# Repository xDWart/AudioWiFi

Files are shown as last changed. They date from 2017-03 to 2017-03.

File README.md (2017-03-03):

# AudioWiFi
Самодельный USB-свисток с микрофоном, STM32 и ESP8266 на борту

**AudioWiFi.ioc** - проект STM32CubeMX (v.4.15.0)

**EWARM\Project.eww** - проект IAR Embedded Workbench IDE for ARM (v.7.70.1)

**EagleCAD\** - проект EagleCAD (v.7.7.0)

**ogg.php** - файл серверной части на PHP

**20170303172953.spx** - пример записанного звука

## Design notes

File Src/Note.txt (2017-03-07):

Минимально рабочие
CSTACK 0x600
HEAP 1400

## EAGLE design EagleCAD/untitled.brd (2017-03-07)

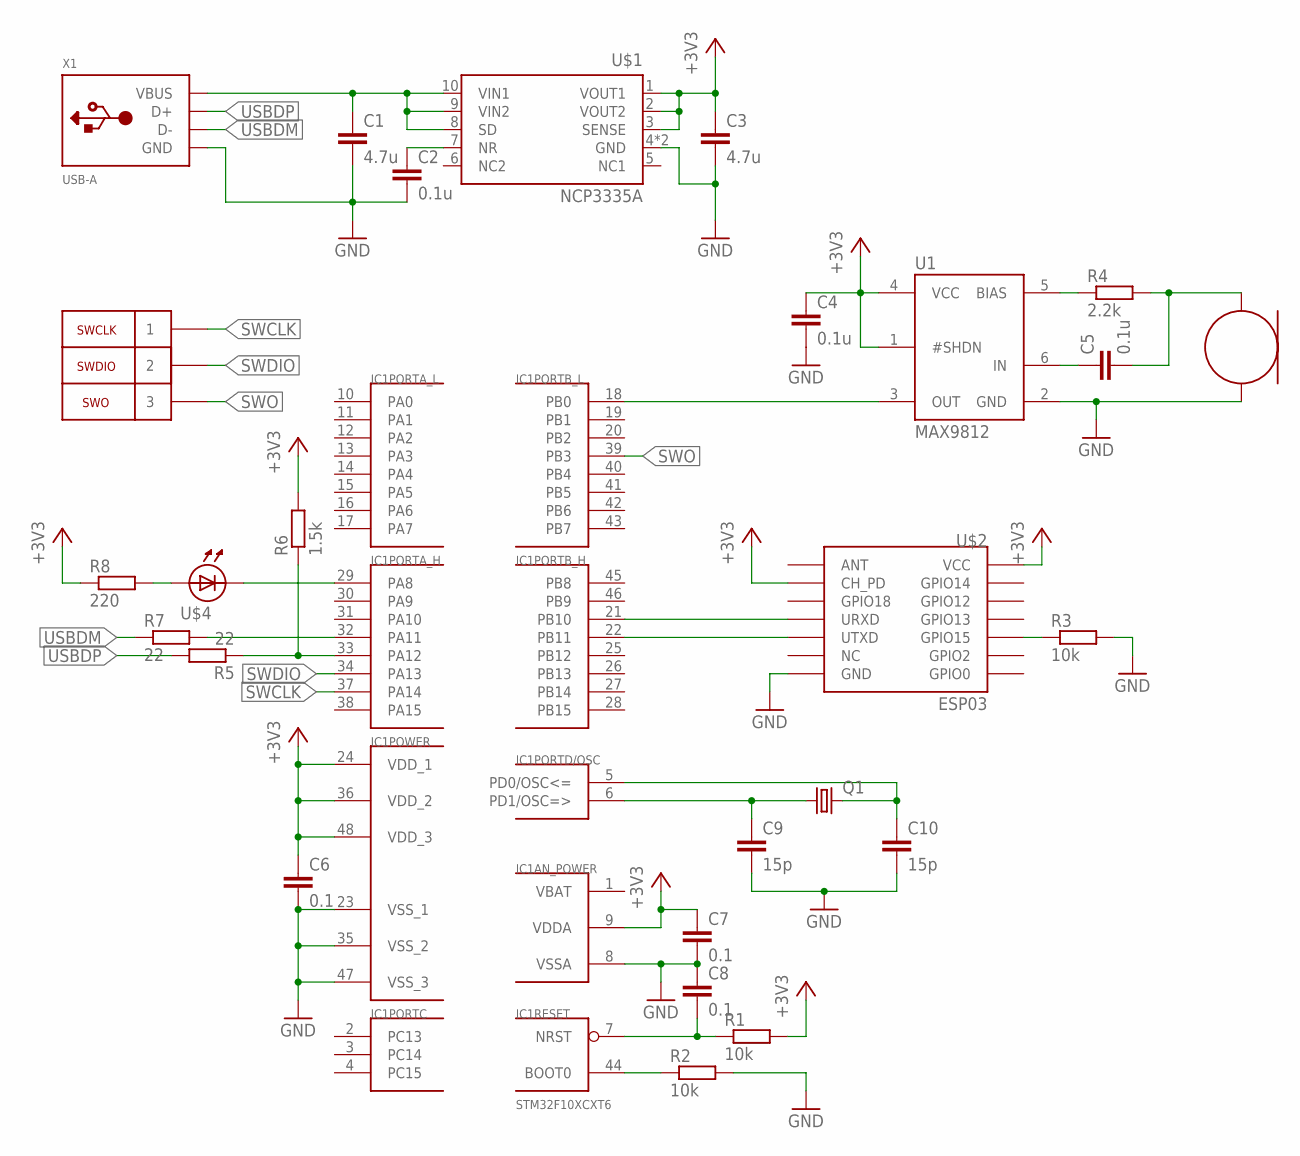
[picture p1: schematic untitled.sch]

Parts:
C1, C3: 4.7u; C0805
C2: 0.1u; C0805
C4, C5: 0.1u; C0603
C6, C7, C8: 0.1; C0805
C9, C10: 15p; C0603
IC1: STM32F10XCXT6; TQFP48
Q1: CRYSTAL; DSX321G
R1, R2, R3: 10k; R0805
R4: 2.2k; R0603
R5, R7: 22; R0805
R6: 1.5k; R0805
R8: 220; R0805
U1: MAX9812; SC-70-6
U$1: NCP3335A; DFN10-3X3
U$2: ESP03
U$3: MIC
U$4: LED1206; R1206
U$5: PLS2-3
X1: USB-A; MOLEX_480371000

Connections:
+3V3: C3.1, C4.1, C6.1, C7.1, IC1.9 (VDDA), IC1.24 (VDD_1), IC1.36 (VDD_2), IC1.48 (VDD_3), R1.2, R6.2, R8.1, U1.1 (#SHDN), U1.4 (VCC), U$1.1 (VOUT1), U$1.2 (VOUT2), U$1.3 (SENSE), U$2.CH_PD, U$2.VCC
GND: C1.2, C2.2, C3.2, C4.2, C6.2, C7.2, C8.1, C9.2, C10.2, IC1.8 (VSSA), IC1.23 (VSS_1), IC1.35 (VSS_2), IC1.47 (VSS_3), R2.2, R3.2, U1.2 (GND), U$1.4 (GND), U$1.EXP (GND), U$2.GND, U$3.P$2, X1.4 (GND)
unnamed: C1.1, U$1.8 (SD), U$1.9 (VIN2), U$1.10 (VIN1), X1.1 (VBUS)
unnamed: C2.1, U$1.7 (NR)
unnamed: C8.2, IC1.7 (NRST), R1.1
unnamed: IC1.44 (BOOT0), R2.1
unnamed: IC1.21 (PB10), U$2.URXD
unnamed: IC1.22 (PB11), U$2.UTXD
unnamed: R3.1, U$2.GPIO15
unnamed: IC1.18 (PB0), U1.3 (OUT)
unnamed: R4.1, U1.5 (BIAS)
unnamed: C5.1, U1.6 (IN)
unnamed: C5.2, R4.2, U$3.P$1
unnamed: IC1.33 (PA12), R5.1, R6.1
unnamed: IC1.32 (PA11), R7.2
unnamed: C9.1, IC1.6 (PD1/OSC=>), Q1.P$1 (1)
unnamed: C10.1, IC1.5 (PD0/OSC<=), Q1.P$3 (2)
unnamed: R8.2, U$4.1
unnamed: IC1.29 (PA8), U$4.2
SWCLK: IC1.37 (PA14), U$5.P$1 (1)
SWDIO: IC1.34 (PA13), U$5.P$2 (2)
SWO: IC1.39 (PB3), U$5.P$3 (3)
USBDM: R7.1, X1.2 (D-)
USBDP: R5.2, X1.3 (D+)
VBAT: IC1.1 (VBAT)

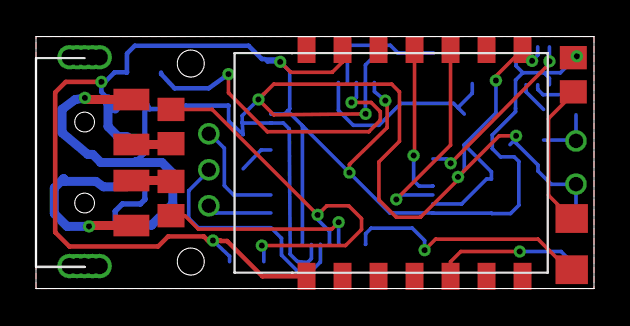
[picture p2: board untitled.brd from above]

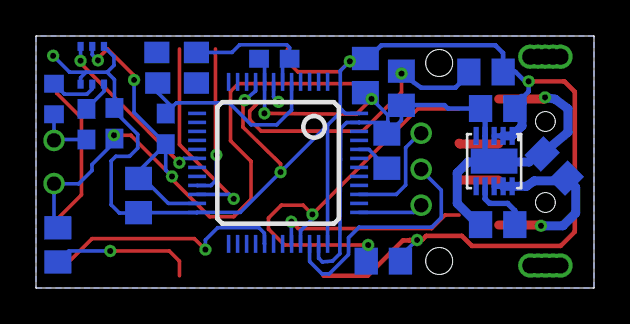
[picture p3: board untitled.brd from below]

Board: 2 copper layers, 31.0 x 14.0 mm, 27 parts (19 on the bottom side), 24 nets.

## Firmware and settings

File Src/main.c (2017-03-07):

/**
  ******************************************************************************
  * File Name          : main.c
  * Description        : Main program body
  ******************************************************************************
  *
  * COPYRIGHT(c) 2017 STMicroelectronics
  *
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
  ******************************************************************************
  */
/* Includes ------------------------------------------------------------------*/
#include "stm32f1xx_hal.h"
#include "usb_device.h"

/* USER CODE BEGIN Includes */
#include "public.h"
#include "my/wifi.h"
#include "my/speexx.h"
#include "my/events.h"

/* USER CODE END Includes */

ADC_HandleTypeDef hadc1;
DMA_HandleTypeDef hdma_adc1;

TIM_HandleTypeDef htim2;
TIM_HandleTypeDef htim3;

UART_HandleTypeDef huart3;
DMA_HandleTypeDef hdma_usart3_tx;

/* USER CODE BEGIN PV */
ADC_HandleTypeDef hadc1;
DMA_HandleTypeDef hdma_adc1;

TIM_HandleTypeDef htim3;

UART_HandleTypeDef huart3;
DMA_HandleTypeDef hdma_usart3_tx;
DMA_HandleTypeDef hdma_usart3_rx;
/* USER CODE END PV */

void SystemClock_Config(void);
void Error_Handler(void);
static void MX_GPIO_Init(void);
static void MX_DMA_Init(void);
static void MX_ADC1_Init(void);
static void MX_TIM2_Init(void);
static void MX_TIM3_Init(void);
static void MX_USART3_UART_Init(void);

/* USER CODE BEGIN PFP */

/* USER CODE END PFP */

int main(void)
{

  /* USER CODE BEGIN 1 */
  ClrEvents();
  Speex_Init();
  /* USER CODE END 1 */

  /* MCU Configuration----------------------------------------------------------*/

  /* Reset of all peripherals, Initializes the Flash interface and the Systick. */
  HAL_Init();

  /* Configure the system clock */
  SystemClock_Config();

  /* Initialize all configured peripherals */
  MX_GPIO_Init();
  MX_DMA_Init();
  MX_ADC1_Init();
  MX_TIM2_Init();
  MX_TIM3_Init();
  MX_USART3_UART_Init();
  MX_USB_DEVICE_Init();

  /* USER CODE BEGIN 2 */
  if(HAL_TIM_Base_Start_IT(&htim2) != HAL_OK) Error_Handler();
  if(HAL_TIM_Base_Start_IT(&htim3) != HAL_OK) Error_Handler();
  if(HAL_ADC_Start_DMA(&hadc1,(uint32_t*)&IN_Buffer[0],FRAME_SIZE*2) != HAL_OK) Error_Handler();
  /* USER CODE END 2 */

  /* Infinite loop */
  /* USER CODE BEGIN WHILE */
  Del_UART_ALL_Nextoperate();
  Add_UART_nextoperate_AT(ATE0,true);
  Add_UART_nextoperate_AT(AT_CWJAP,true);
  
  HAL_Delay(1000);
  Led_off; 
  HAL_UART_Receive_IT(&huart3,&UART_RxByte,1);
  SetEvent(EVNT_UART_SEND,EVENT_DONE); 
  while (1)
  {   
    if (TestEvent_Done(EVNT_UART_SEND)) {
      UART_send();
    }

    if (TestEvent_Done(EVNT_UART_RECEIVE)) {
      UART_parser();
    }
    
    EncodingVoice();

    if (TestEvent_Done(EVNT_VAD_DETECT)) {
      VAD_detect = false;
    }
    
    if (TestEvent_Done(EVNT_LED_SIGNAL)) {
        Led_inv;
        if (VAD_detect) SetEvent(EVNT_LED_SIGNAL,200);
          else if (ReadySendData) SetEvent(EVNT_LED_SIGNAL,1000);
                             else SetEvent(EVNT_LED_SIGNAL,3000);
    }    

  /* USER CODE END WHILE */

  /* USER CODE BEGIN 3 */
  }
  /* USER CODE END 3 */

}

/** System Clock Configuration
*/
void SystemClock_Config(void)
{

  RCC_OscInitTypeDef RCC_OscInitStruct;
  RCC_ClkInitTypeDef RCC_ClkInitStruct;
  RCC_PeriphCLKInitTypeDef PeriphClkInit;

  RCC_OscInitStruct.OscillatorType = RCC_OSCILLATORTYPE_HSE;
  RCC_OscInitStruct.HSEState = RCC_HSE_ON;
  RCC_OscInitStruct.HSEPredivValue = RCC_HSE_PREDIV_DIV1;
  RCC_OscInitStruct.PLL.PLLState = RCC_PLL_ON;
  RCC_OscInitStruct.PLL.PLLSource = RCC_PLLSOURCE_HSE;
  RCC_OscInitStruct.PLL.PLLMUL = RCC_PLL_MUL9;
  if (HAL_RCC_OscConfig(&RCC_OscInitStruct) != HAL_OK)
  {
    Error_Handler();
  }

  RCC_ClkInitStruct.ClockType = RCC_CLOCKTYPE_HCLK|RCC_CLOCKTYPE_SYSCLK
                              |RCC_CLOCKTYPE_PCLK1|RCC_CLOCKTYPE_PCLK2;
  RCC_ClkInitStruct.SYSCLKSource = RCC_SYSCLKSOURCE_PLLCLK;
  RCC_ClkInitStruct.AHBCLKDivider = RCC_SYSCLK_DIV1;
  RCC_ClkInitStruct.APB1CLKDivider = RCC_HCLK_DIV2;
  RCC_ClkInitStruct.APB2CLKDivider = RCC_HCLK_DIV1;
  if (HAL_RCC_ClockConfig(&RCC_ClkInitStruct, FLASH_LATENCY_2) != HAL_OK)
  {
    Error_Handler();
  }

  PeriphClkInit.PeriphClockSelection = RCC_PERIPHCLK_ADC|RCC_PERIPHCLK_USB;
  PeriphClkInit.AdcClockSelection = RCC_ADCPCLK2_DIV6;
  PeriphClkInit.UsbClockSelection = RCC_USBCLKSOURCE_PLL_DIV1_5;
  if (HAL_RCCEx_PeriphCLKConfig(&PeriphClkInit) != HAL_OK)
  {
    Error_Handler();
  }

  HAL_SYSTICK_Config(HAL_RCC_GetHCLKFreq()/1000);

  HAL_SYSTICK_CLKSourceConfig(SYSTICK_CLKSOURCE_HCLK);

  /* SysTick_IRQn interrupt configuration */
  HAL_NVIC_SetPriority(SysTick_IRQn, 0, 0);
}

/* ADC1 init function */
static void MX_ADC1_Init(void)
{

  ADC_ChannelConfTypeDef sConfig;

    /**Common config 
    */
  hadc1.Instance = ADC1;
  hadc1.Init.ScanConvMode = ADC_SCAN_DISABLE;
  hadc1.Init.ContinuousConvMode = DISABLE;
  hadc1.Init.DiscontinuousConvMode = DISABLE;
  hadc1.Init.ExternalTrigConv = ADC_EXTERNALTRIGCONV_T3_TRGO;
  hadc1.Init.DataAlign = ADC_DATAALIGN_RIGHT;
  hadc1.Init.NbrOfConversion = 1;
  if (HAL_ADC_Init(&hadc1) != HAL_OK)
  {
    Error_Handler();
  }

    /**Configure Regular Channel 
    */
  sConfig.Channel = ADC_CHANNEL_8;
  sConfig.Rank = 1;
  sConfig.SamplingTime = ADC_SAMPLETIME_1CYCLE_5;
  if (HAL_ADC_ConfigChannel(&hadc1, &sConfig) != HAL_OK)
  {
    Error_Handler();
  }

}

/* TIM2 init function */
static void MX_TIM2_Init(void)
{

  TIM_ClockConfigTypeDef sClockSourceConfig;
  TIM_MasterConfigTypeDef sMasterConfig;

  htim2.Instance = TIM2;
  htim2.Init.Prescaler = 1;
  htim2.Init.CounterMode = TIM_COUNTERMODE_UP;
  htim2.Init.Period = 35999;
  htim2.Init.ClockDivision = TIM_CLOCKDIVISION_DIV1;
  if (HAL_TIM_Base_Init(&htim2) != HAL_OK)
  {
    Error_Handler();
  }

  sClockSourceConfig.ClockSource = TIM_CLOCKSOURCE_INTERNAL;
  if (HAL_TIM_ConfigClockSource(&htim2, &sClockSourceConfig) != HAL_OK)
  {
    Error_Handler();
  }

  sMasterConfig.MasterOutputTrigger = TIM_TRGO_RESET;
  sMasterConfig.MasterSlaveMode = TIM_MASTERSLAVEMODE_DISABLE;
  if (HAL_TIMEx_MasterConfigSynchronization(&htim2, &sMasterConfig) != HAL_OK)
  {
    Error_Handler();
  }

}

/* TIM3 init function */
static void MX_TIM3_Init(void)
{

  TIM_ClockConfigTypeDef sClockSourceConfig;
  TIM_MasterConfigTypeDef sMasterConfig;

  htim3.Instance = TIM3;
  htim3.Init.Prescaler = 0;
  htim3.Init.CounterMode = TIM_COUNTERMODE_UP;
  htim3.Init.Period = 8999;
  htim3.Init.ClockDivision = TIM_CLOCKDIVISION_DIV1;
  if (HAL_TIM_Base_Init(&htim3) != HAL_OK)
  {
    Error_Handler();
  }

  sClockSourceConfig.ClockSource = TIM_CLOCKSOURCE_INTERNAL;
  if (HAL_TIM_ConfigClockSource(&htim3, &sClockSourceConfig) != HAL_OK)
  {
    Error_Handler();
  }

  sMasterConfig.MasterOutputTrigger = TIM_TRGO_UPDATE;
  sMasterConfig.MasterSlaveMode = TIM_MASTERSLAVEMODE_DISABLE;
  if (HAL_TIMEx_MasterConfigSynchronization(&htim3, &sMasterConfig) != HAL_OK)
  {
    Error_Handler();
  }

}

/* USART3 init function */
static void MX_USART3_UART_Init(void)
{

  huart3.Instance = USART3;
  huart3.Init.BaudRate = 115200;
  huart3.Init.WordLength = UART_WORDLENGTH_8B;
  huart3.Init.StopBits = UART_STOPBITS_1;
  huart3.Init.Parity = UART_PARITY_NONE;
  huart3.Init.Mode = UART_MODE_TX_RX;
  huart3.Init.HwFlowCtl = UART_HWCONTROL_NONE;
  huart3.Init.OverSampling = UART_OVERSAMPLING_16;
  if (HAL_UART_Init(&huart3) != HAL_OK)
  {
    Error_Handler();
  }

}

/** 
  * Enable DMA controller clock
  */
static void MX_DMA_Init(void) 
{
  /* DMA controller clock enable */
  __HAL_RCC_DMA1_CLK_ENABLE();

  /* DMA interrupt init */
  /* DMA1_Channel1_IRQn interrupt configuration */
  HAL_NVIC_SetPriority(DMA1_Channel1_IRQn, 0, 0);
  HAL_NVIC_EnableIRQ(DMA1_Channel1_IRQn);
  /* DMA1_Channel2_IRQn interrupt configuration */
  HAL_NVIC_SetPriority(DMA1_Channel2_IRQn, 0, 0);
  HAL_NVIC_EnableIRQ(DMA1_Channel2_IRQn);

}

/** Configure pins as 
        * Analog 
        * Input 
        * Output
        * EVENT_OUT
        * EXTI
*/
static void MX_GPIO_Init(void)
{

  GPIO_InitTypeDef GPIO_InitStruct;

  /* GPIO Ports Clock Enable */
  __HAL_RCC_GPIOD_CLK_ENABLE();
  __HAL_RCC_GPIOB_CLK_ENABLE();
  __HAL_RCC_GPIOA_CLK_ENABLE();

  /*Configure GPIO pin Output Level */
  HAL_GPIO_WritePin(GPIOA, GPIO_PIN_8, GPIO_PIN_RESET);

  /*Configure GPIO pin : PA8 */
  GPIO_InitStruct.Pin = GPIO_PIN_8;
  GPIO_InitStruct.Mode = GPIO_MODE_OUTPUT_PP;
  GPIO_InitStruct.Speed = GPIO_SPEED_FREQ_LOW;
  HAL_GPIO_Init(GPIOA, &GPIO_InitStruct);

}

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


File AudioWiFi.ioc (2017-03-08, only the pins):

Mcu.UserName=STM32F103CBTx
PA11.Signal=USB_DM
PA12.Signal=USB_DP
PA13.Signal=SYS_JTMS-SWDIO
PA14.Signal=SYS_JTCK-SWCLK
PA8.Signal=GPIO_Output
PB0.Signal=ADCx_IN8
PB10.Signal=USART3_TX
PB11.Signal=USART3_RX
PB3.Signal=SYS_JTDO-TRACESWO
PD0-OSC_IN.Signal=RCC_OSC_IN
PD1-OSC_OUT.Signal=RCC_OSC_OUT

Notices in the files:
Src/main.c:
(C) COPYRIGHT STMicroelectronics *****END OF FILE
